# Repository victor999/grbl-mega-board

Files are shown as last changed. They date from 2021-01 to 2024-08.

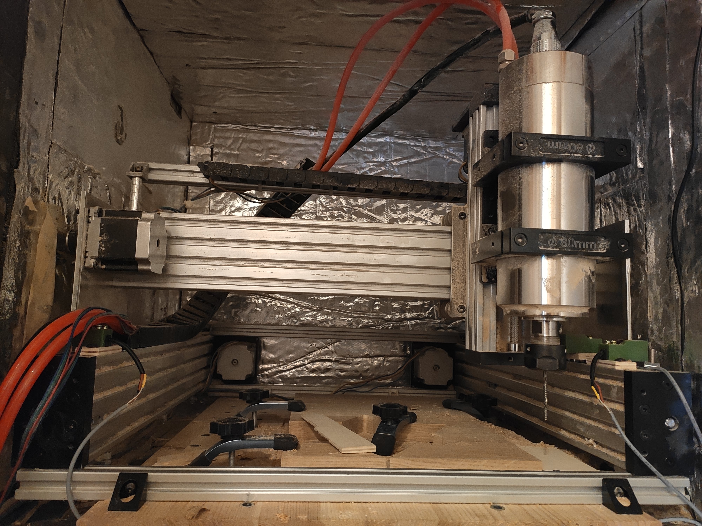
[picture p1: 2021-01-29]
machine-photos/IMG_20210129_105626.jpg

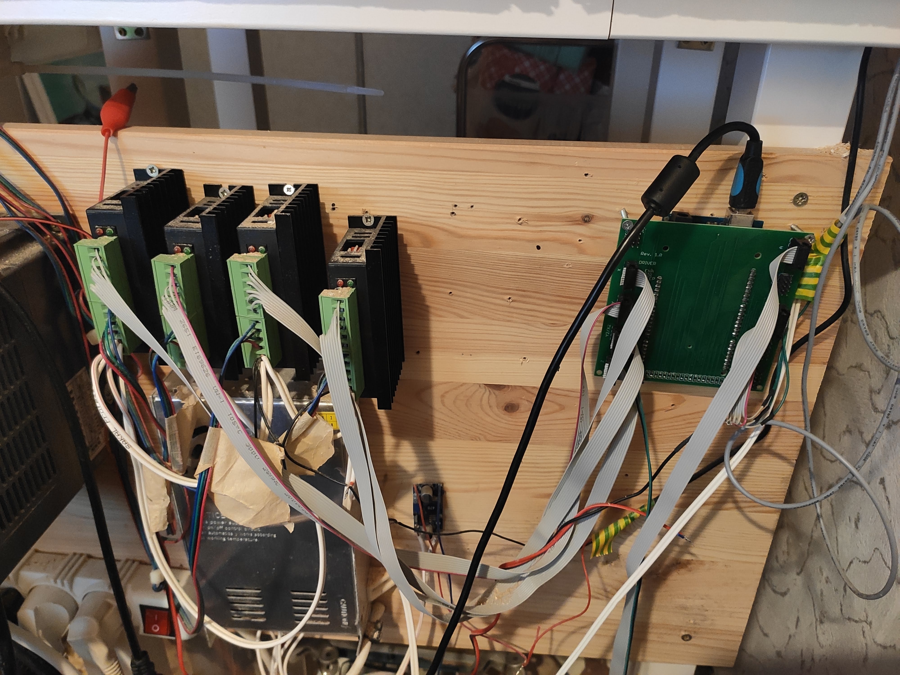
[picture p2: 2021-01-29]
machine-photos/IMG_20210129_105606.jpg

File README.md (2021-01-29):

# grbl-mega-board
Board for grbl-mega 5 axis project

https://github.com/fra589/grbl-Mega-5X

Designed in Eagle

Connectors designed with approach to direct connection to drivers without swapping wires - first pin on connector, first pin on driver and so on

Tested in XYZXAB CNC configuration with MIN limit switches and TB6600 drivers. 

It means double X axis with separate limit switches, so no problems with squaring

Can be configured also for double Y or whatever you want

Current config is for XYZX

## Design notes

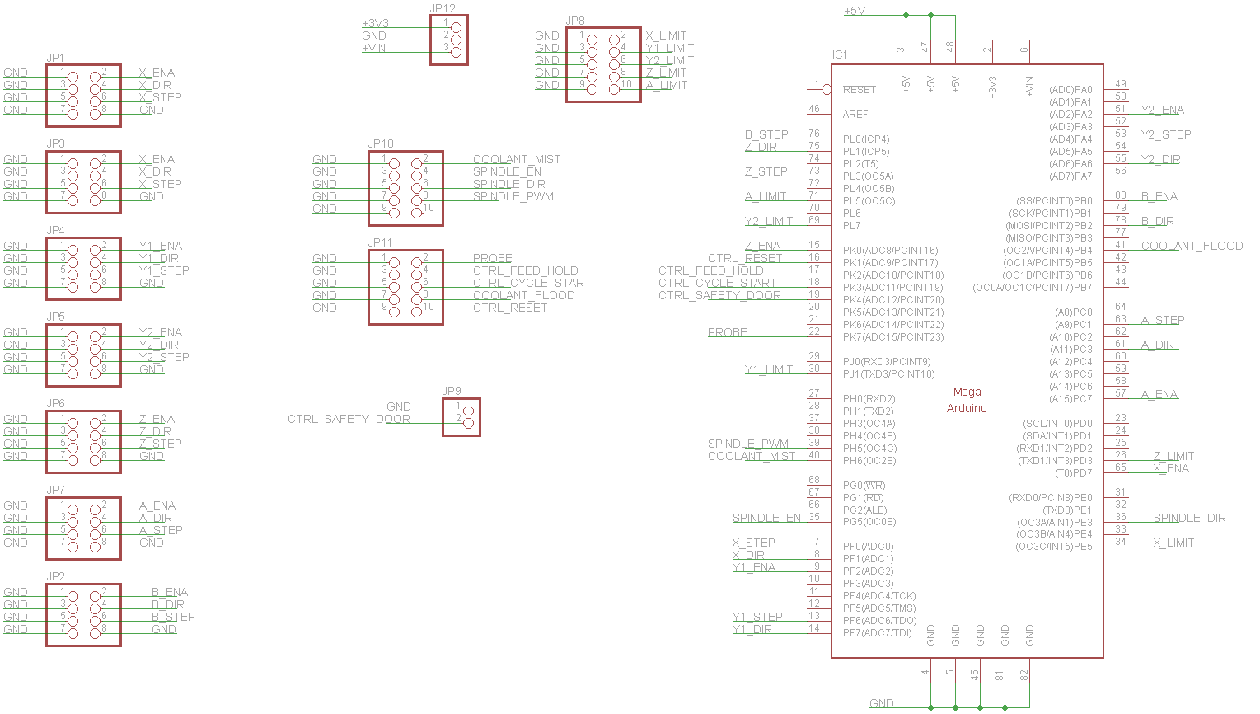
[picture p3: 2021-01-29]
PCB-design/schematic.png

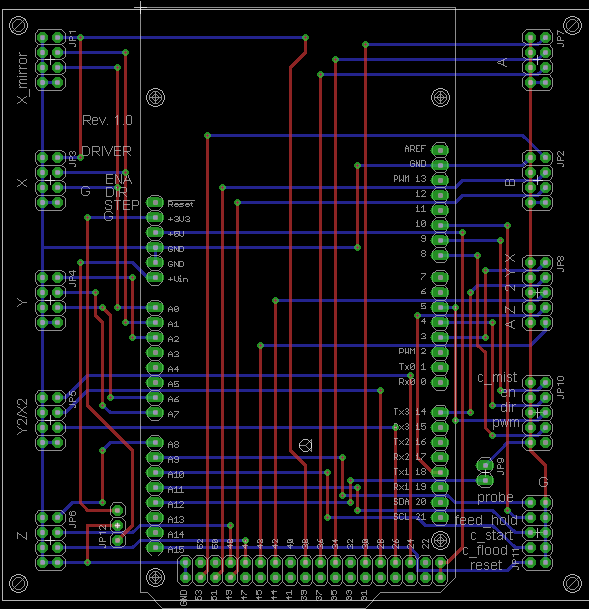
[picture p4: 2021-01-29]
PCB-design/board.png

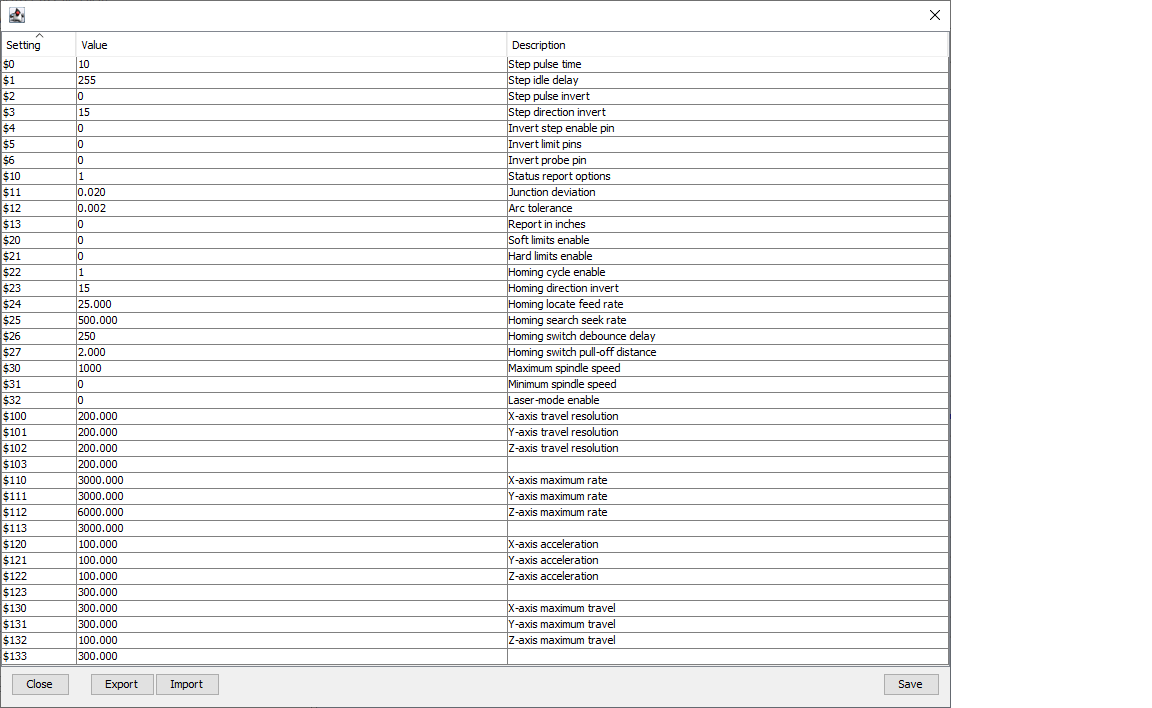
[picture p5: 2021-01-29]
config/firmware settings.png

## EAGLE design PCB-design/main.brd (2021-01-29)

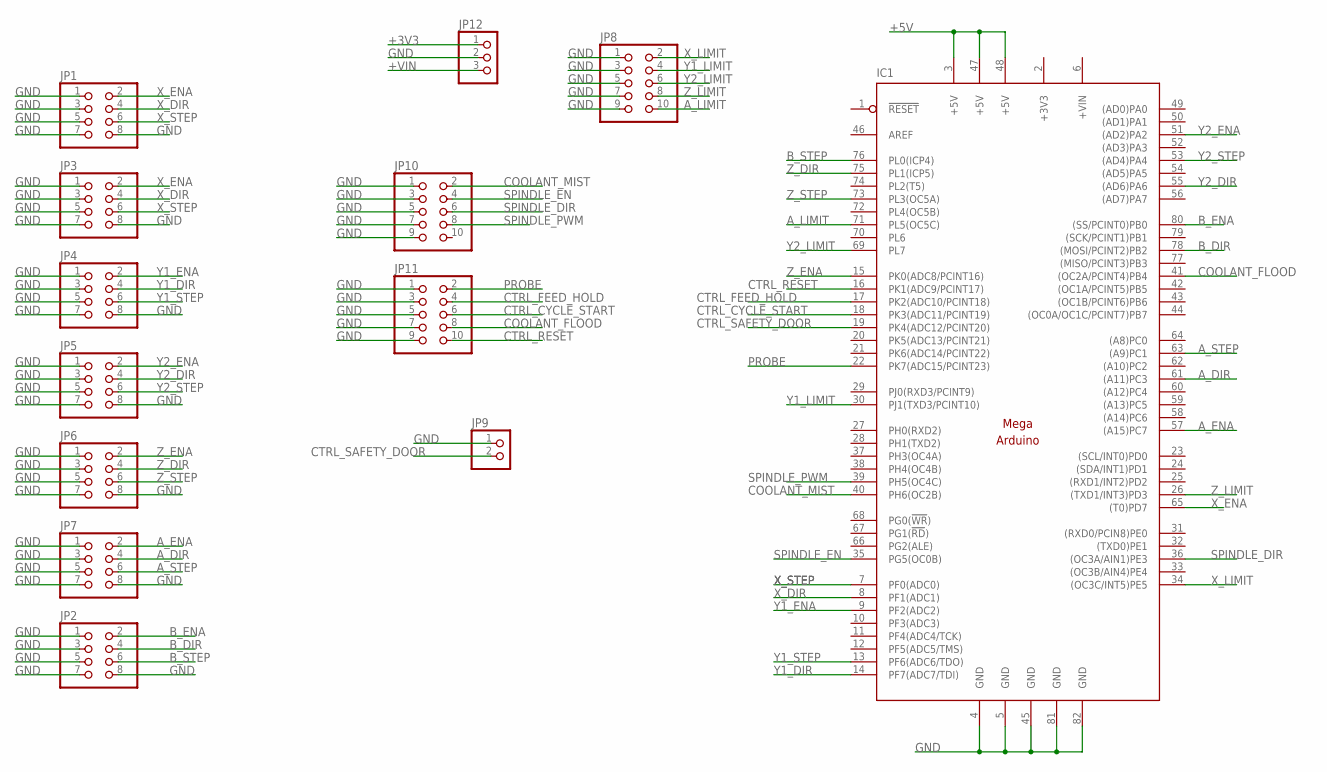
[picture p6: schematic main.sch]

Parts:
IC1: MEGAARDUINO_1; MEGA_ARDUINO
JP1, JP2, JP3, JP4, JP5, JP6, JP7: PINHD-2X4; 2X04
JP8, JP10, JP11: PINHD-2X5; 2X05
JP9: PINHD-1X2; 1X02
JP12: PINHD-1X3; 1X03

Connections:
+3V3: IC1.2 (+3V3), JP12.1
+5V: IC1.3 (+5V), IC1.47 (+5V), IC1.48 (+5V)
+VIN: IC1.6 (+VIN), JP12.3
A_DIR: IC1.61 ((A11)PC3), JP7.4
A_ENA: IC1.57 ((A15)PC7), JP7.2
A_LIMIT: IC1.71 (PL5(OC5C)), JP8.10
A_STEP: IC1.63 ((A9)PC1), JP7.6
B_DIR: IC1.78 ((MOSI/PCINT2)PB2), JP2.4
B_ENA: IC1.80 ((SS/PCINT0)PB0), JP2.2
B_STEP: IC1.76 (PL0(ICP4)), JP2.6
COOLANT_FLOOD: IC1.41 ((OC2A/PCINT4)PB4), JP11.8
COOLANT_MIST: IC1.40 (PH6(OC2B)), JP10.2
CTRL_CYCLE_START: IC1.18 (PK3(ADC11/PCINT19)), JP11.6
CTRL_FEED_HOLD: IC1.17 (PK2(ADC10/PCINT18)), JP11.4
CTRL_RESET: IC1.16 (PK1(ADC9/PCINT17)), JP11.10
CTRL_SAFETY_DOOR: IC1.19 (PK4(ADC12/PCINT20)), JP9.2
GND: IC1.4 (GND), IC1.5 (GND), IC1.45 (GND), IC1.81 (GND), IC1.82 (GND), JP1.1, JP1.3, JP1.5, JP1.7, JP1.8, JP2.1, JP2.3, JP2.5, JP2.7, JP2.8, JP3.1, JP3.3, JP3.5, JP3.7, JP3.8, JP4.1, JP4.3, JP4.5, JP4.7, JP4.8, JP5.1, JP5.3, JP5.5, JP5.7, JP5.8, JP6.1, JP6.3, JP6.5, JP6.7, JP6.8, JP7.1, JP7.3, JP7.5, JP7.7, JP7.8, JP8.1, JP8.3, JP8.5, JP8.7, JP8.9, JP9.1, JP10.1, JP10.3, JP10.5, JP10.7, JP10.9, JP11.1, JP11.3, JP11.5, JP11.7, JP11.9, JP12.2
PROBE: IC1.22 (PK7(ADC15/PCINT23)), JP11.2
SPINDLE_DIR: IC1.36 ((OC3A/AIN1)PE3), JP10.6
SPINDLE_EN: IC1.35 (PG5(OC0B)), JP10.4
SPINDLE_PWM: IC1.39 (PH5(OC4C)), JP10.8
X_DIR: IC1.8 (PF1(ADC1)), JP1.4, JP3.4
X_ENA: IC1.65 ((T0)PD7), JP1.2, JP3.2
X_LIMIT: IC1.34 ((OC3C/INT5)PE5), JP8.2
X_STEP: IC1.7 (PF0(ADC0)), JP1.6, JP3.6
Y1_DIR: IC1.14 (PF7(ADC7/TDI)), JP4.4
Y1_ENA: IC1.9 (PF2(ADC2)), JP4.2
Y1_LIMIT: IC1.30 (PJ1(TXD3/PCINT10)), JP8.4
Y1_STEP: IC1.13 (PF6(ADC6/TDO)), JP4.6
Y2_DIR: IC1.55 ((AD6)PA6), JP5.4
Y2_ENA: IC1.51 ((AD2)PA2), JP5.2
Y2_LIMIT: IC1.69 (PL7), JP8.6
Y2_STEP: IC1.53 ((AD4)PA4), JP5.6
Z_DIR: IC1.75 (PL1(ICP5)), JP6.4
Z_ENA: IC1.15 (PK0(ADC8/PCINT16)), JP6.2
Z_LIMIT: IC1.26 ((TXD1/INT3)PD3), JP8.8
Z_STEP: IC1.73 (PL3(OC5A)), JP6.6

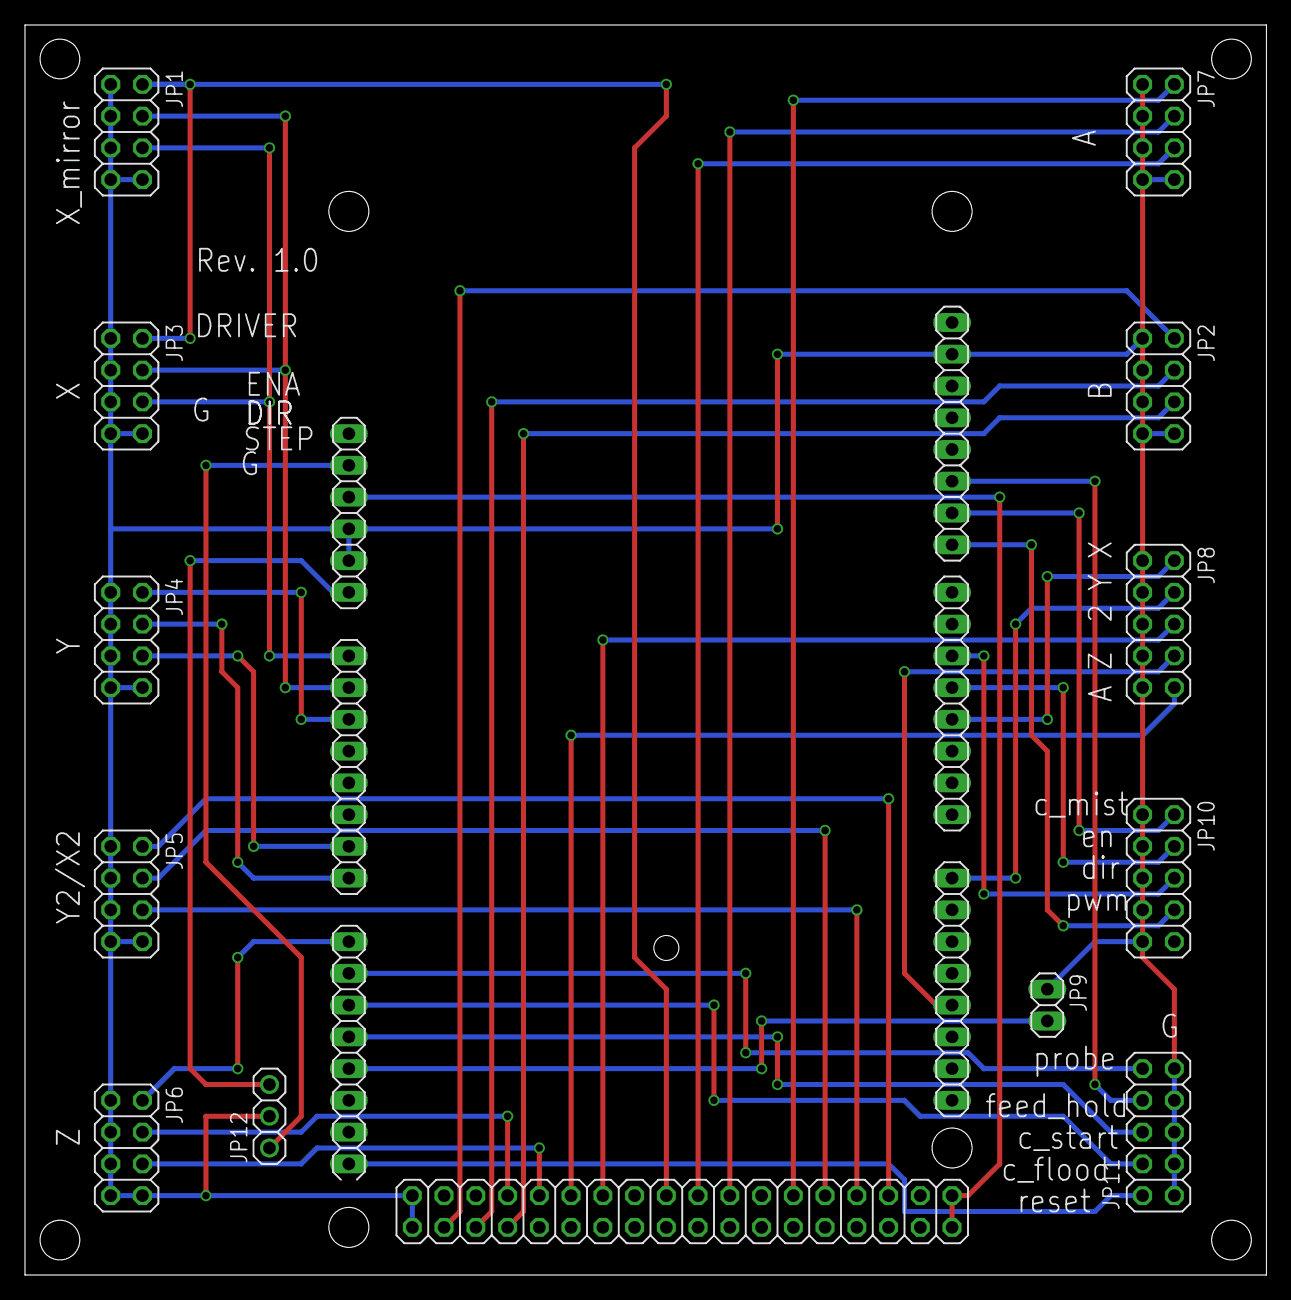
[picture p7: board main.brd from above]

Board: 2 copper layers, 99.3 x 100.0 mm, 13 parts (0 on the bottom side), 37 nets.

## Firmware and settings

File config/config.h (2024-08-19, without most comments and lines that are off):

#define config_h
#include "grbl.h" // For Arduino IDE compatibility.
#define BAUD_RATE 115200
#define DEFAULTS_GENERIC
#define CPU_MAP_2560_RAMPS_BOARD
#define N_AXIS 4        // Number of axes (3 to 6)
#define N_AXIS_LINEAR 4 // Number of linears axis, must be <= N_AXIS
#define AXIS_1 0        // Axis indexing value. Must start with 0 and be continuous.
#define AXIS_1_NAME 'X' // Axis names must be in X, Y, Z, A, B, C, U, V, W, D, E & H.
#define AXIS_2 1
#define AXIS_2_NAME 'Y'
#define AXIS_3 2
#define AXIS_3_NAME 'Z'
#if N_AXIS <3
  #error "N_AXIS must be >= 3. N_AXIS < 3 is not implemented."
#endif
#if N_AXIS > 3
  #define AXIS_4 3
  #define AXIS_4_NAME 'X' // Letter of axis number 4
#endif
#if N_AXIS > 4
  #define AXIS_5 4
  #define AXIS_5_NAME 'B' // Letter of axis number 5
#endif
#if N_AXIS > 5
  #define AXIS_6 5
  #define AXIS_6_NAME 'C' // Letter of axis number 6
#endif
#if N_AXIS > 6
  #error "N_AXIS must be <= 6. N_AXIS > 6 is not implemented."
#endif
#define SPINDLE_PWM_ON_D8
#define CMD_RESET 0x18 // ctrl-x.
#define CMD_STATUS_REPORT '?'
#define CMD_CYCLE_START '~'
#define CMD_FEED_HOLD '!'
#define CMD_SAFETY_DOOR 0x84
#define CMD_JOG_CANCEL  0x85
#define CMD_DEBUG_REPORT 0x86 // Only when DEBUG enabled, sends debug report in '{}' braces.
#define CMD_FEED_OVR_RESET 0x90         // Restores feed override value to 100%.
#define CMD_FEED_OVR_COARSE_PLUS 0x91
#define CMD_FEED_OVR_COARSE_MINUS 0x92
#define CMD_FEED_OVR_FINE_PLUS  0x93
#define CMD_FEED_OVR_FINE_MINUS  0x94
#define CMD_RAPID_OVR_RESET 0x95        // Restores rapid override value to 100%.
#define CMD_RAPID_OVR_MEDIUM 0x96
#define CMD_RAPID_OVR_LOW 0x97
#define CMD_SPINDLE_OVR_RESET 0x99      // Restores spindle override value to 100%.
#define CMD_SPINDLE_OVR_COARSE_PLUS 0x9A
#define CMD_SPINDLE_OVR_COARSE_MINUS 0x9B
#define CMD_SPINDLE_OVR_FINE_PLUS 0x9C
#define CMD_SPINDLE_OVR_FINE_MINUS 0x9D
#define CMD_SPINDLE_OVR_STOP 0x9E
#define CMD_COOLANT_FLOOD_OVR_TOGGLE 0xA0
#define CMD_COOLANT_MIST_OVR_TOGGLE 0xA1
#define HOMING_INIT_LOCK // Comment to disable
#if N_AXIS == 4 // 4 axis : homing
  #define HOMING_CYCLE_0 (1<<AXIS_3) // Home Z axis first to clear workspace.
  #define HOMING_CYCLE_1 ((1<<AXIS_1)|(1<<AXIS_4)) // Home X axis (double)
  #define HOMING_CYCLE_2 (1<<AXIS_2) // Home Y axis  // OPTIONAL: uncomment to move only Y at a time.
#elif N_AXIS == 5 // 5 axis : homing
  #define HOMING_CYCLE_0 (1<<AXIS_3) // Home Z axis first to clear workspace.
  #define HOMING_CYCLE_1 ((1<<AXIS_1)|(1<<AXIS_2))     // OPTIONAL: uncomment to move X,Y at the same time.
#elif N_AXIS == 6 // 6 axis : homing
  #define HOMING_CYCLE_0 (1<<AXIS_3) // Home Z axis first to clear workspace.
  #define HOMING_CYCLE_1 ((1<<AXIS_1)|(1<<AXIS_2))     // OPTIONAL: uncomment to move X,Y at the same time.
#else // Classic 3 axis
  #define HOMING_CYCLE_0 (1<<AXIS_3) // Home Z axis first to clear workspace.
  #define HOMING_CYCLE_1 ((1<<AXIS_1)|(1<<AXIS_2))     // OPTIONAL: uncomment to move X,Y at the same time.
#endif
#define N_HOMING_LOCATE_CYCLE 3 // Integer (1-128)
#define HOMING_SINGLE_AXIS_COMMANDS // Default disabled. Uncomment to enable.
#define N_STARTUP_LINE 2 // Integer (1-2)
#define N_DECIMAL_COORDVALUE_INCH 4 // Coordinate or position value in inches
#define N_DECIMAL_COORDVALUE_MM   3 // Coordinate or position value in mm
#define N_DECIMAL_RATEVALUE_INCH  1 // Rate or velocity value in in/min
#define N_DECIMAL_RATEVALUE_MM    0 // Rate or velocity value in mm/min
#define N_DECIMAL_SETTINGVALUE    3 // Decimals for floating point setting values
#define N_DECIMAL_RPMVALUE        0 // RPM value in rotations per min.
#define MESSAGE_PROBE_COORDINATES // Enabled by default. Comment to disable.
#define SAFETY_DOOR_SPINDLE_DELAY 4.0 // Float (seconds)
#define SAFETY_DOOR_COOLANT_DELAY 1.0 // Float (seconds)
#define CHECK_LIMITS_AT_INIT
#define DEFAULT_FEED_OVERRIDE           100 // 100%. Don't change this value.
#define MAX_FEED_RATE_OVERRIDE          200 // Percent of programmed feed rate (100-255). Usually 120% or 200%
#define MIN_FEED_RATE_OVERRIDE           10 // Percent of programmed feed rate (1-100). Usually 50% or 1%
#define FEED_OVERRIDE_COARSE_INCREMENT   10 // (1-99). Usually 10%.
#define FEED_OVERRIDE_FINE_INCREMENT      1 // (1-99). Usually 1%.
#define DEFAULT_RAPID_OVERRIDE  100 // 100%. Don't change this value.
#define RAPID_OVERRIDE_MEDIUM    50 // Percent of rapid (1-99). Usually 50%.
#define RAPID_OVERRIDE_LOW       25 // Percent of rapid (1-99). Usually 25%.
#define DEFAULT_SPINDLE_SPEED_OVERRIDE    100 // 100%. Don't change this value.
#define MAX_SPINDLE_SPEED_OVERRIDE        200 // Percent of programmed spindle speed (100-255). Usually 200%.
#define MIN_SPINDLE_SPEED_OVERRIDE         10 // Percent of programmed spindle speed (1-100). Usually 10%.
#define SPINDLE_OVERRIDE_COARSE_INCREMENT  10 // (1-99). Usually 10%.
#define SPINDLE_OVERRIDE_FINE_INCREMENT     1 // (1-99). Usually 1%.
#define RESTORE_OVERRIDES_AFTER_PROGRAM_END // Default enabled. Comment to disable.
#define REPORT_FIELD_BUFFER_STATE // Default enabled. Comment to disable.
#define REPORT_FIELD_PIN_STATE // Default enabled. Comment to disable.
#define REPORT_FIELD_CURRENT_FEED_SPEED // Default enabled. Comment to disable.
#define REPORT_FIELD_WORK_COORD_OFFSET // Default enabled. Comment to disable.
#define REPORT_FIELD_OVERRIDES // Default enabled. Comment to disable.
#define REPORT_FIELD_LINE_NUMBERS // Default enabled. Comment to disable.
#define REPORT_OVR_REFRESH_BUSY_COUNT 20  // (1-255)
#define REPORT_OVR_REFRESH_IDLE_COUNT 10  // (1-255) Must be less than or equal to the busy count
#define REPORT_WCO_REFRESH_BUSY_COUNT 30  // (2-255)
#define REPORT_WCO_REFRESH_IDLE_COUNT 10  // (2-255) Must be less than or equal to the busy count
#define ACCELERATION_TICKS_PER_SECOND 100
#define ADAPTIVE_MULTI_AXIS_STEP_SMOOTHING  // Default enabled. Comment to disable.
#define TOOL_LENGTH_OFFSET_AXIS AXIS_3 // Default z-axis. Valid values are AXIS_1, AXIS_2, or AXIS_3.
#define MINIMUM_JUNCTION_SPEED 0.0 // (mm/min)
#define MINIMUM_FEED_RATE 1.0 // (mm/min)
#define N_ARC_CORRECTION 12 // Integer (1-255)
#define ARC_ANGULAR_TRAVEL_EPSILON 5E-7 // Float (radians)
#define DWELL_TIME_STEP 50 // Integer (1-255) (milliseconds)
#define ENABLE_RESTORE_EEPROM_WIPE_ALL         // '$RST=*' Default enabled. Comment to disable.
#define ENABLE_RESTORE_EEPROM_DEFAULT_SETTINGS // '$RST=$' Default enabled. Comment to disable.
#define ENABLE_RESTORE_EEPROM_CLEAR_PARAMETERS // '$RST=#' Default enabled. Comment to disable.
#define ENABLE_BUILD_INFO_WRITE_COMMAND // '$I=' Default enabled. Comment to disable.
#define FORCE_BUFFER_SYNC_DURING_EEPROM_WRITE // Default enabled. Comment to disable.
#define FORCE_BUFFER_SYNC_DURING_WCO_CHANGE // Default enabled. Comment to disable.
#define PARKING_AXIS AXIS_3 // Define which axis that performs the parking motion
#define PARKING_TARGET -5.0 // Parking axis target. In mm, as machine coordinate [-max_travel,0].
#define PARKING_RATE 500.0 // Parking fast rate after pull-out in mm/min.
#define PARKING_PULLOUT_RATE 100.0 // Pull-out/plunge slow feed rate in mm/min.
#define PARKING_PULLOUT_INCREMENT 5.0 // Spindle pull-out and plunge distance in mm. Incremental distance.
#define SLEEP_DURATION 5.0 // Float (0.25 - 61.0) seconds before sleep mode is executed.
#define DISABLE_LASER_DURING_HOLD // Default enabled. Comment to disable.
#define N_PIECES 4  // Integer (1-4). Number of piecewise lines used in script solution.
#define RPM_MAX  11686.4  // Max RPM of model. $30 > RPM_MAX will be limited to RPM_MAX.
#define RPM_MIN  202.5    // Min RPM of model. $31 < RPM_MIN will be limited to RPM_MIN.
#define RPM_POINT12  6145.4  // Used N_PIECES >=2. Junction point between lines 1 and 2.
#define RPM_POINT23  9627.8  // Used N_PIECES >=3. Junction point between lines 2 and 3.
#define RPM_POINT34  10813.9 // Used N_PIECES = 4. Junction point between lines 3 and 4.
#define RPM_LINE_A1  3.197101e-03  // Used N_PIECES >=1. A and B constants of line 1.
#define RPM_LINE_B1  -3.526076e-1
#define RPM_LINE_A2  1.722950e-2   // Used N_PIECES >=2. A and B constants of line 2.
#define RPM_LINE_B2  8.588176e+01
#define RPM_LINE_A3  5.901518e-02  // Used N_PIECES >=3. A and B constants of line 3.
#define RPM_LINE_B3  4.881851e+02
#define RPM_LINE_A4  1.203413e-01  // Used N_PIECES = 4. A and B constants of line 4.
#define RPM_LINE_B4  1.151360e+03

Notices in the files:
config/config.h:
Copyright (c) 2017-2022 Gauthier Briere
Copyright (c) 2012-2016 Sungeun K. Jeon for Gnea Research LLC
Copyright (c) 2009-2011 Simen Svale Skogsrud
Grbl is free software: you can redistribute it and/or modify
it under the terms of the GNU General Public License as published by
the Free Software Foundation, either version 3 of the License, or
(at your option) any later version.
